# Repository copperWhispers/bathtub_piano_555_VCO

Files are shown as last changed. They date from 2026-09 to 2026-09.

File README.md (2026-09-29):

# bathtub_piano_555_VCO
bathtub tune-able analog keyboard based around a 555 timer chip used in PPM configuration.

Story Telling of the journey:
https://youtu.be/zMRLficPjbc

NE555:
https://www.ti.com/lit/ds/symlink/ne555.pdf

KiCAD Schematic and Layout attached.

Also attached a rough notes document which is the doc I wrote into as I designed this circuit, you can see it as an in depth technical version of the journey presented in the video.







References:

Ref1: notes and their frequencies
https://www.idrumtune.com/ultimate-guide-to-musical-frequencies/

Ref2: a complicated VCO + various waveform generators module. +/-12V
https://musicfromouterspace.com/analogsynth_new/VCO20090724REV0/VCO20090724REV0.html

Ref3: The basics of Oscillators and VCOs well explained step by step with circuits to be used +/12V
https://sound-au.com/project162.htm

Ref4: 555 Timer Datasheet.
https://www.ti.com/lit/ds/symlink/na555.pdf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

Ref5: Virtual grounds and examples.
https://tangentsoft.com/elec/vgrounds.html

Ref6: Potentiometers.
https://www.jotrin.com/technology/details/potentiometer-pinout-symbol-wiring-and-working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

Ref7: Inverting OPAMP topology.
https://electrosome.com/inverting-amplifier-using-opamp/

Ref8: RMS Formulae:
https://www.electronics-tutorials.ws/accircuits/rms-voltage.html

Ref9: Tim Stinchcomb Tri to SIne.
https://www.timstinchcombe.co.uk/index.php?pge=trisin

Ref10: TI Analog Engineer’s Pocket Reference.
https://www.ti.com/product-category/amplifiers/analog-engineers-pocket-reference-guide.html

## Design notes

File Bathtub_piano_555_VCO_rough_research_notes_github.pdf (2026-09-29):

I am working on making a video about a circuit that could generate a tone so that I can then build everything from there, I want this to be a sawtooth generator but it needs to produce set frequencies corresponding to the 12 fundamental notes.

## Music Theory:

Ref1

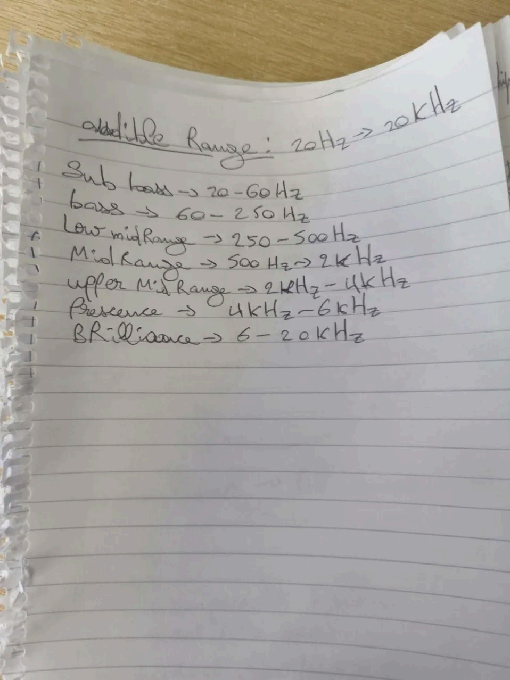
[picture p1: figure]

This sawtooth generator thus has to be variable easily so that I can get it to play any note,

## Sawtooth Generator:

I found out that sawtooth generators usually work by
having a current source charge up a capacitor,
followed by a comparator triggering once the capacitor get to a certain point,
The comparator’s signal then makes a switch which is responsible for discharging the capacitor activate,
This discharges the capacitor so that the cycle can start again, and the frequency is then set by how quickly you charge and discharge the capacitor.

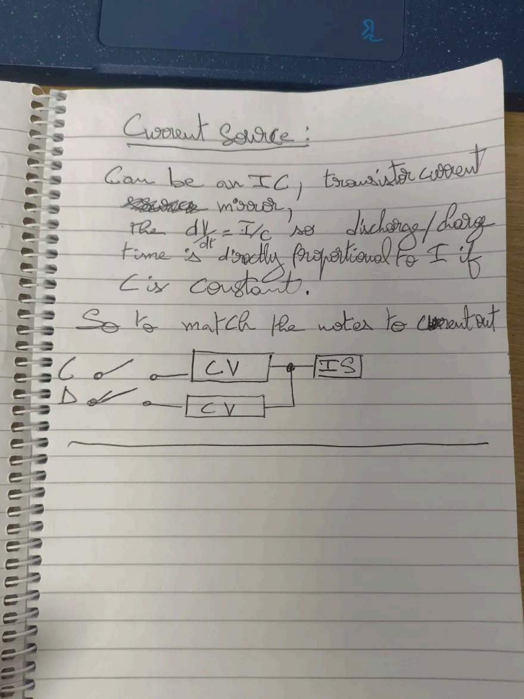
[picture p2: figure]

I then looked into how current sources work for this kind of utilisation, they can be coming from a transistor current mirror circuit,
I then drew that I would need a switch per note which would lead to a certain current source being provided to the capacitor for charging,
Or if using a voltage controlled oscillator then it would be a certain voltage per switch.

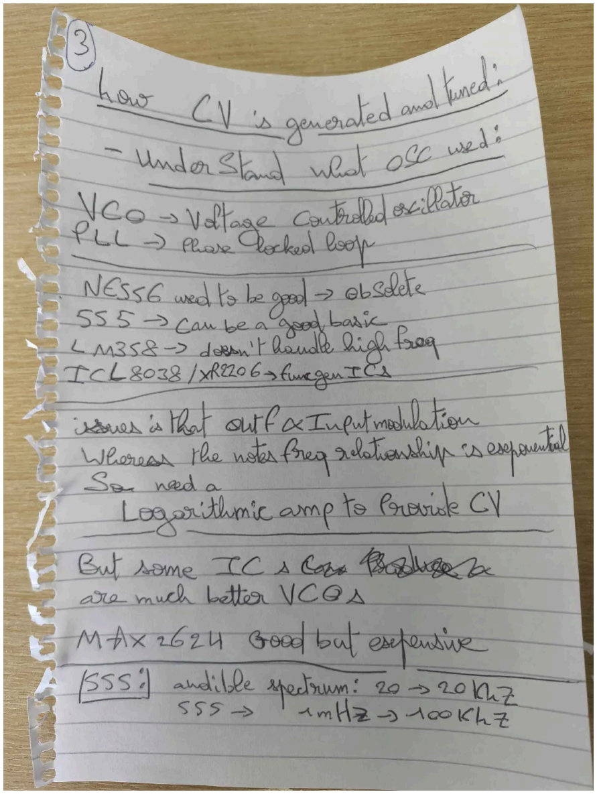
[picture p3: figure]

I then researched what oscillator I was going to use to get a clear idea of the control current or voltage required,
I ended up choosing the 555 timer for it’s low cost, high availability, high amount of documentation and the fact that it can handle 1mHz up to 100kHz, I learned about it from Ref3 and investigated the components listed in the article.

I then deep dived into the 555 timer through it’s datasheet , I came to learn that my desired configuration would be the PPM setup, and that the frequency which is related to the positioning of the pulses could be varied by applying a control voltage to the CONT pin,

This sounded very simple and so I decided to stick with this idea and just use trimmers on the input so that I could tune the instrument by having a frequency meter on the output and tuning each note individually,

I also discovered that the opamp seems to output a 5V pk to pk signal from the graphs, this is to be tested and I believe it is dependent on the power given to the ic, so I should check the datasheet further, but I will be more than fine with my virtual ground setup because it will be ac coupled which will get rid of the dc bias and thus the signal should fit in the virtual gnd’s realm.

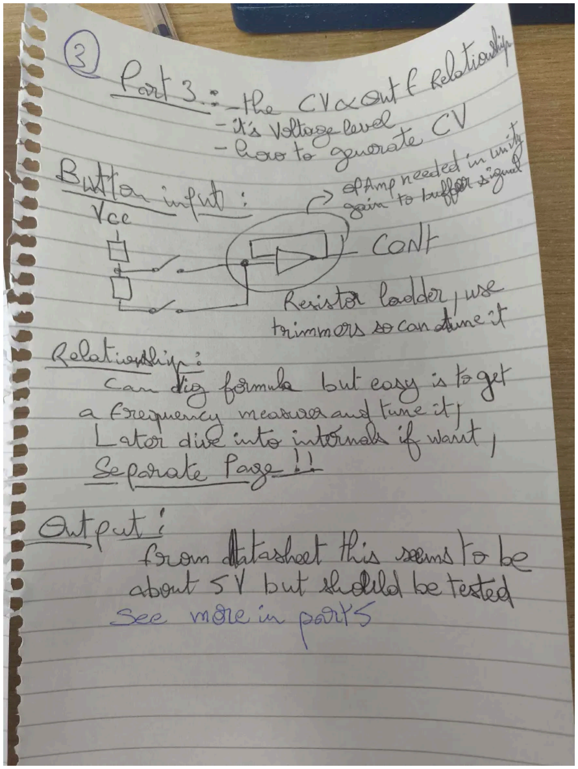
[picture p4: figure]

Here I looked deeper into what method I would use to control the input of the 555 timer to control it’s frequency,

I then thought I could analyse the formula in a deep dive format but that would have to wait as it is a complicated topic,

And lastly setup the plan regarding how I would morph the oscillator’s output to fit the audio amplifier,

I then looked at the datasheet and saw that the chip can handle 12V.

And thought I could also generate a virtual gnd from the 12V supply so that I can then morph the signal to my audio amp’s requirement through an inverting amplifier combined with an ac coupling capacitor.

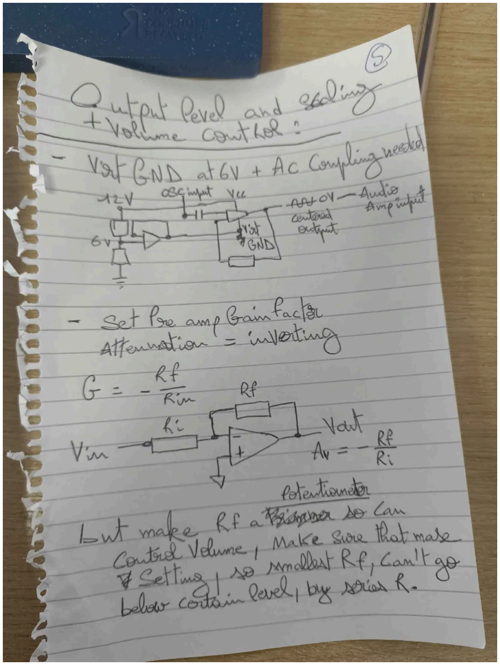
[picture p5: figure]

Once all of this was done, I drafted a quick inverting + virt gnd + ac coupling circuit idea which will be ready for testing, I also wrote down the maths for attenuation and circuit topology.

## Schematic Design:

### Part Organisation:

From my parts drawer I have the following components available:
NE5532ADR, I will use this chip for the pre amp. https://www.ti.com/lit/ds/symlink/ne5532.pdf?ts=1787995293486&ref_url=https%253A%252 F%252Fcz.mouser.com%252F (https://www.ti.com/lit/ds/symlink/ne5532.pdf?ts=1787995293486)

TL072HIDDFR, I will use this chip for the Virt GND buffer.https://www.ti.com/lit/ds/symlink/tl071h.pdf?ts=1788006096240&ref_url=https%253A%252F%252Fwww.mouser.de%252F (https://www.ti.com/lit/ds/symlink/tl071h.pdf?ts=1788006096240)

All sorts of passives,
NE555.

### 12V PSU:

For now this is just a 12V supply from mains AC, nothing to do here,

### 6V Vdiv Virt GND:

This is about taking the 12V rail, having a Voltage divider network and then buffering the mid point to be used as a Virtual mid point ground,

From Ref5:

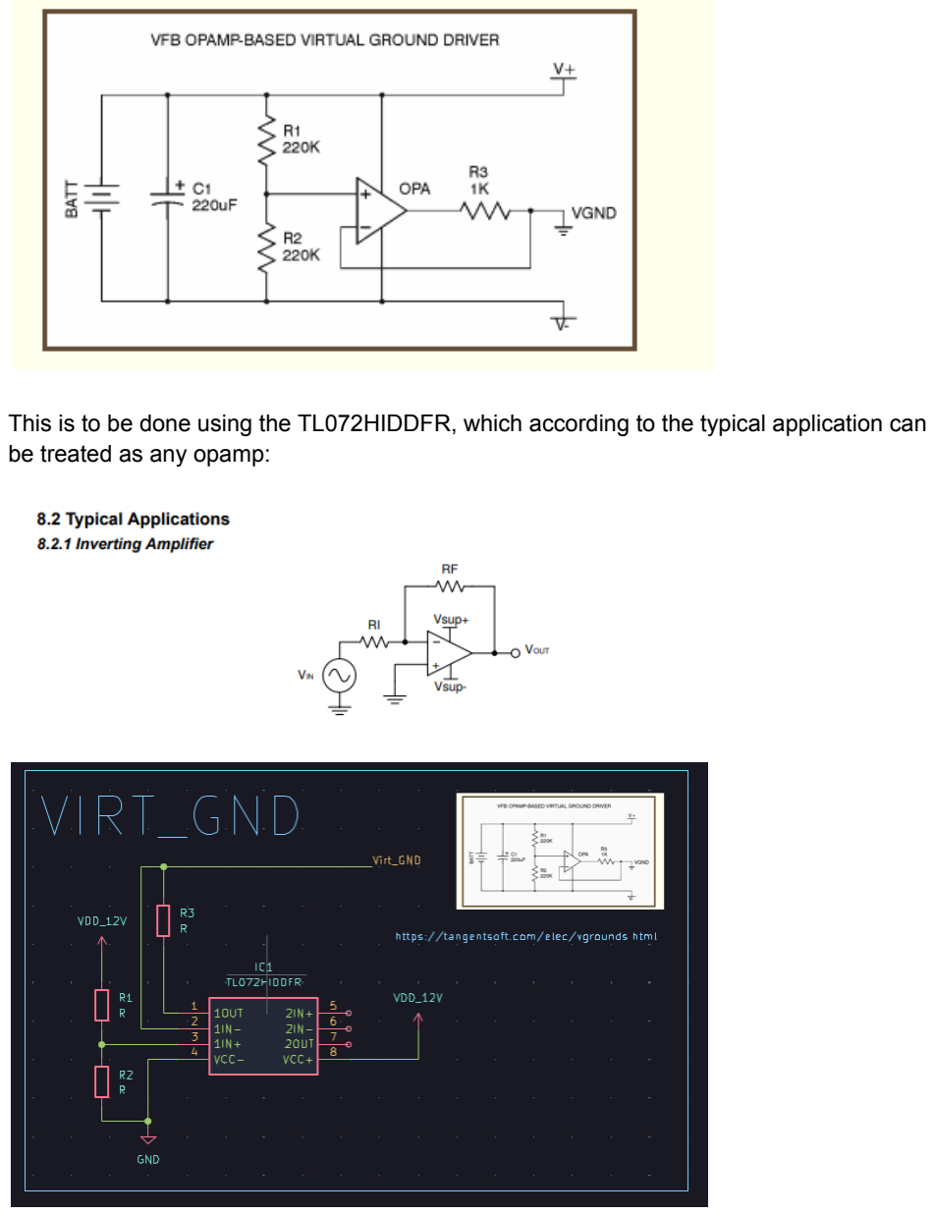
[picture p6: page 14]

This is to be done using the TL072HIDDFR, which according to the typical application can be treated as any opamp:

### Resistors Ladder with Buttons + Buffered:

For this we need to use trimmers so that we can tune the instrument, as I am bypassing the maths for efficiency sake I will be setting an arbitrary trimmer value on the breadboard and seeing if it works then just adjust later if needed.
From Ref6, this is how a potentiometer works:

So you have the input go to pin 1, then the follow up goes to pin2 and then GND to pin 3. This creates a voltage divider, which means that pin 2 will output a variable voltage set to wherever you have the point, we don’t actually need a cascading ladder which would induce issues such as adjusting the first trimmer would cascade the values of the next but here instead we can have each note be its own trimmer, which makes the job much simpler.

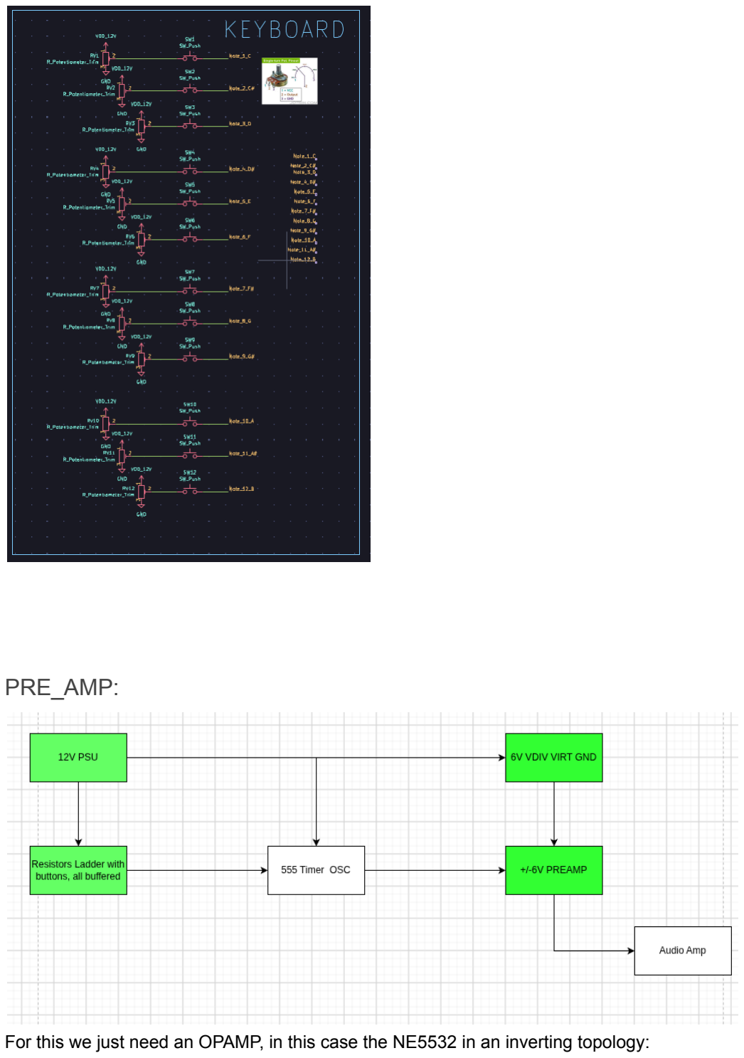
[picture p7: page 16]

### PRE_AMP:

For this we just need an OPAMP, in this case the NE5532 in an inverting topology:

Gain is then: Gain = - (Rf / R1)
So if we predict the 555 timer to output 5V and we want that to become 0.4V: 0.4 / 5 = 0.08,
Setting Rf to 100k for reference we get:
-0.08 = (100k / R1) Which transforms into: R1 = -(100k / (-0.08))
This would mean R1 = 1,250,000, which is too big of a value for my liking, so I will change RF to 8k and now R1 is 100k, clean numbers.
The negative sign here indicates that the signal flips polarity.

However I didn’t account for the fact that this is about comparing 0.4Vrms with whatever the rms of 5V is, so they need to both be rms not one in pkpk and one in rms,

Rms formulae:

So 5Vpk = ~ 3.5Vrms

So now the attenuation is 0.4 / 3.5 = ~ 0.1,
R1 = -(10k / (-0.1))
R1 = 100k

I rounded some figures as it doesn’t need to be completely accurate at this stage and there will be some breadboarding done later too

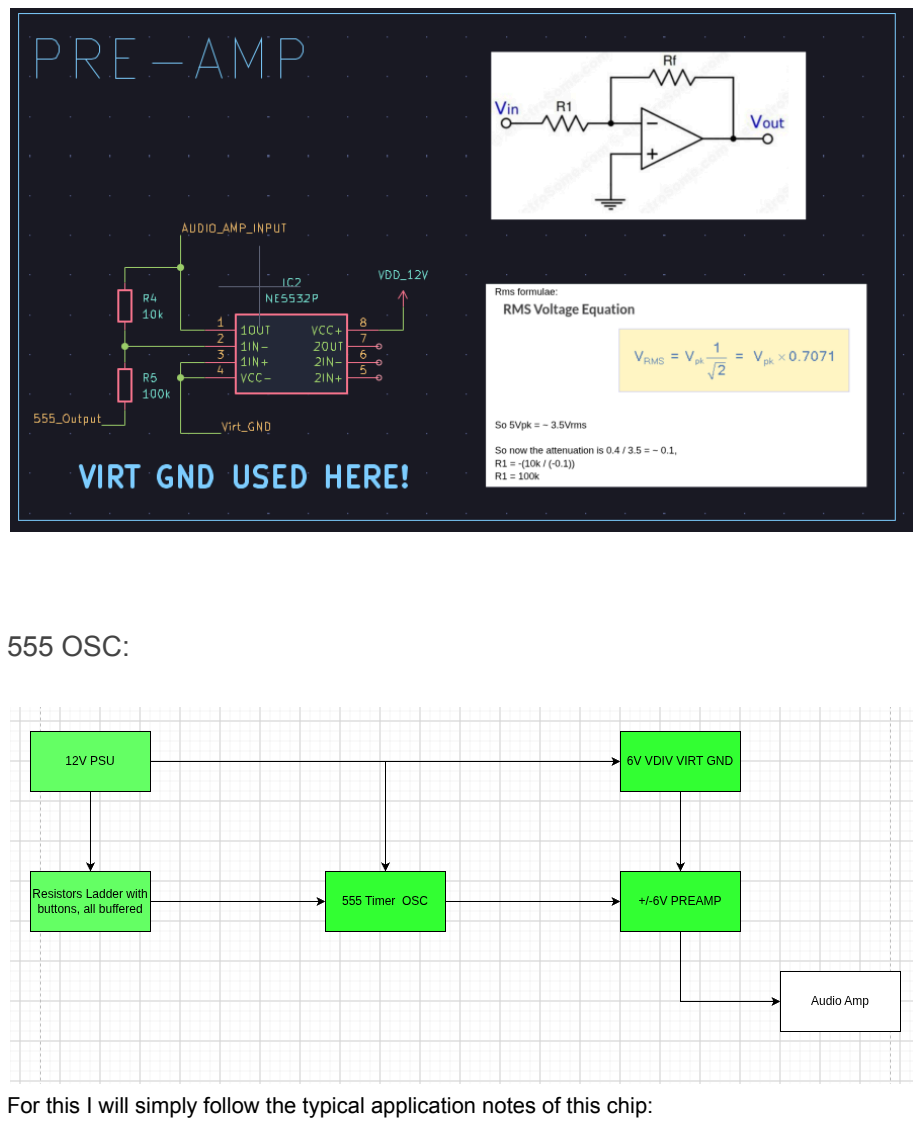
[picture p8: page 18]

### 555 OSC:

For this I will simply follow the typical application notes of this chip:

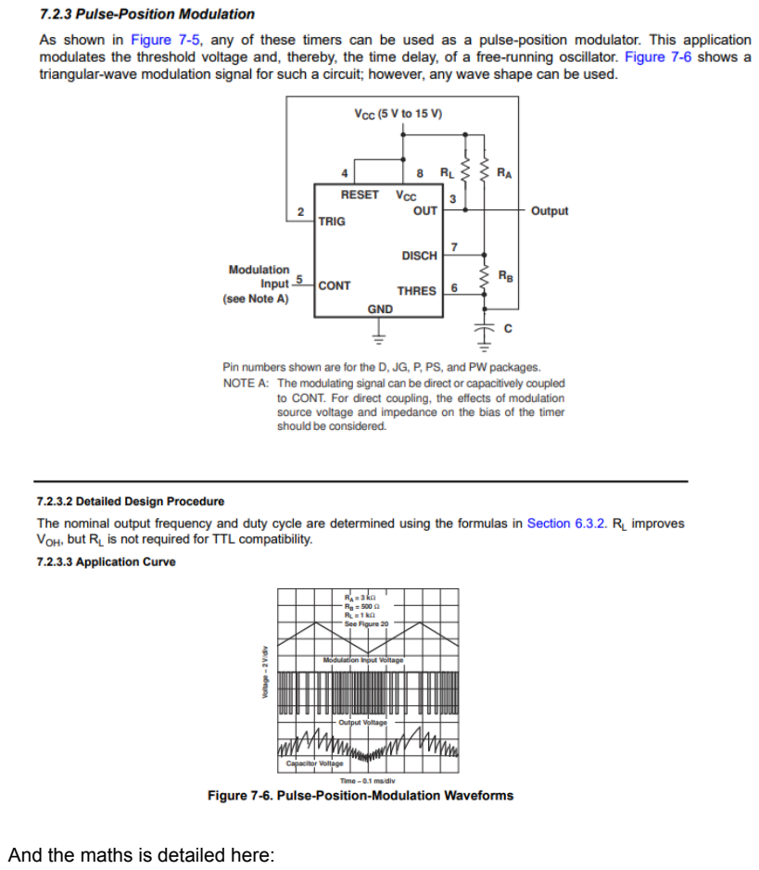
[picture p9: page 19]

And the maths is detailed here:

So from my understanding frequency = 1.44 / (RA + 2RB) * C

However for PPM configuration:

The modulation input changes the voltage thresholds which then changes the frequency as the charge/discharge will happen at a different rate, so this seems like a bit of a rabbit hole and I think the most efficient way to solve this is to follow the typical application graph values of:
RA = 3k ohms, RB = 500 ohms, RL = 1k ohms

Then on a breadboard setup just one pot trimmer Vdiv input to the modulation input, figure out what R values give me C3 through the 12 notes up to B3, take notes of them and then select the trimmers based on this experiment.

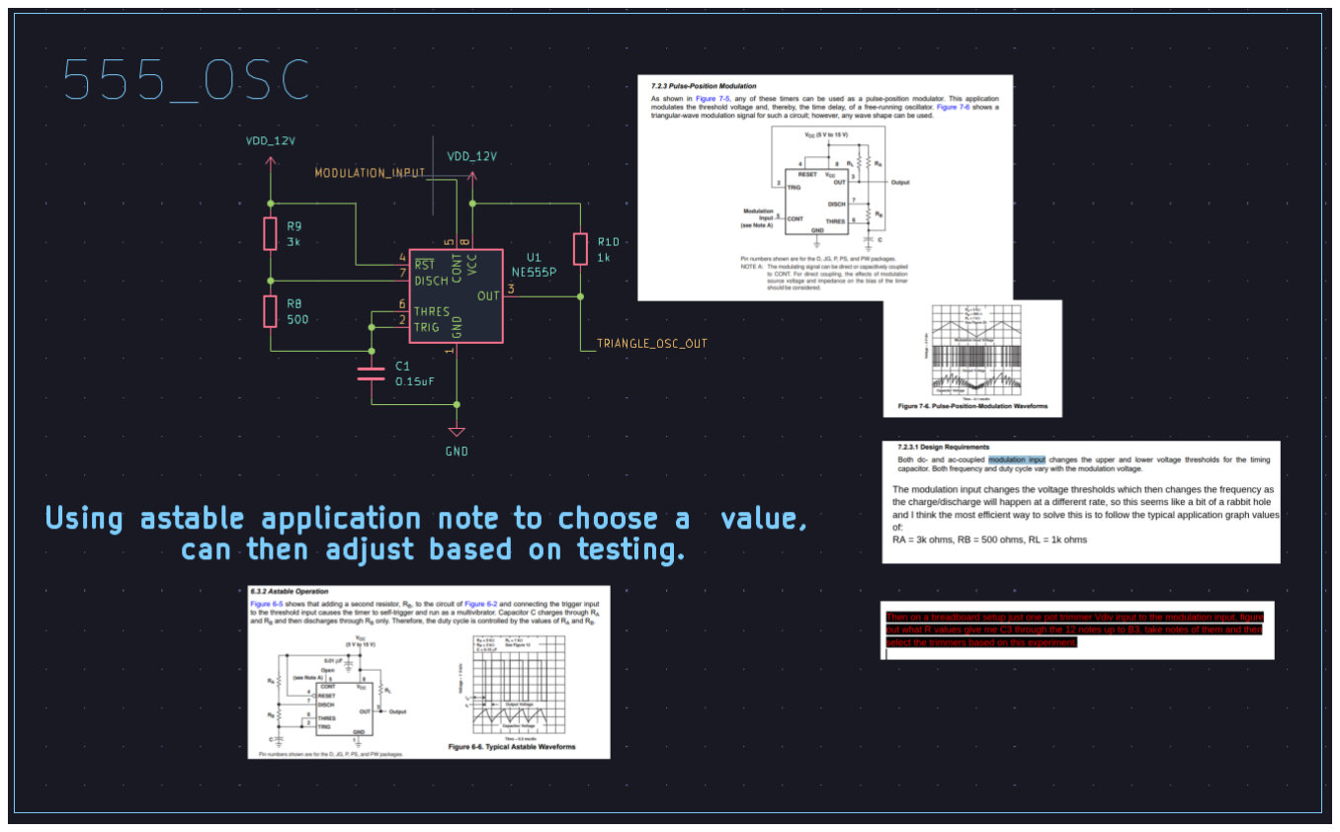
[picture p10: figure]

### Tidy up and Connect to Audio Amp:

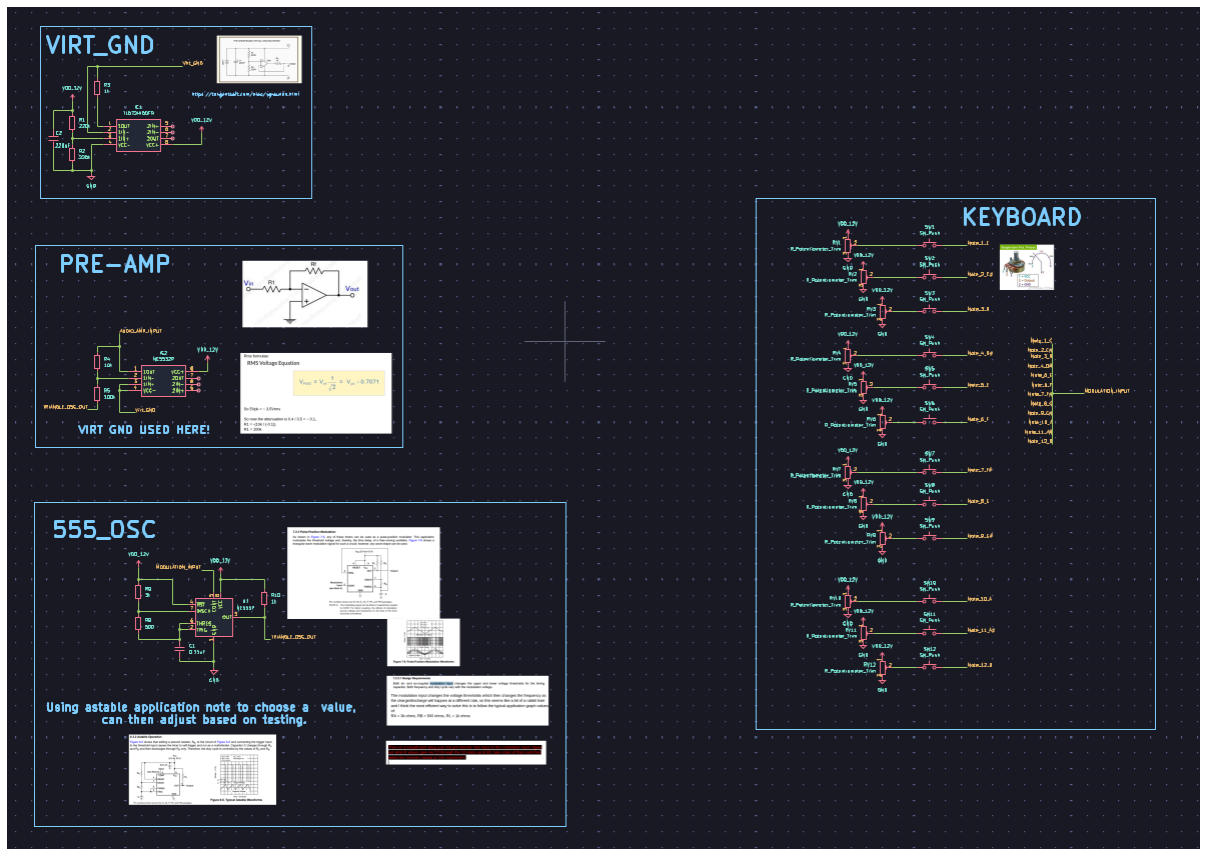
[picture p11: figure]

## Design Error, Research Rectification, Learning:

### In/Out Impedance:

I then realised through another build that potentially the virtual ground and pre-amp aren't actually needed,

Maybe just a Resistor divider would be sufficient for converting the 12V PWM output to the input required for the audio amp,

Then an AC Coupling cap is used to remove the DC offset and center the signal around 0V,

So I came to this decision by learning about Load and Source impedance and it’s ratios relationship with the delivered voltage:

Load Z / Source Z = Load to Source Z ratio.

VL = VS * (RL / RS + RL) -> so the resistors ratio define the percentage of V that is delivered.
Here’s a model of the ratio and its relationship with delivered voltage:

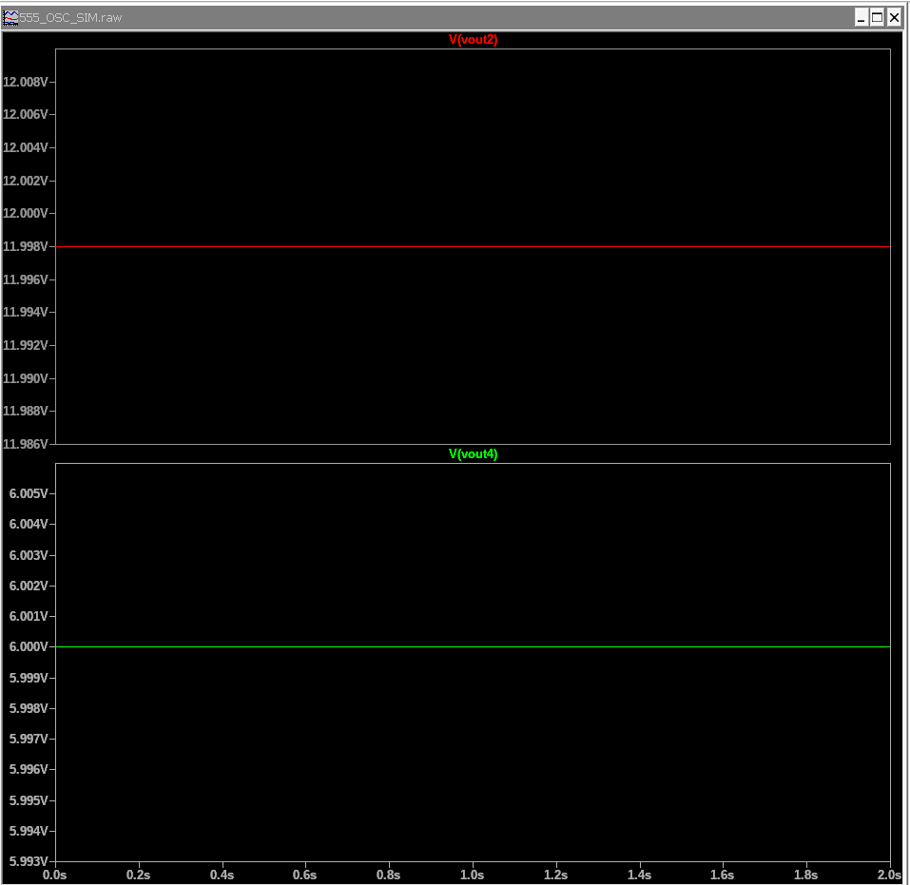
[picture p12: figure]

As you can see, having a good load to source ratio means that more voltage is present at the load, if the load = source then you would lose half of the voltage at the load, this is crucial for high precision sensing equipment as the sample is already so small that we want to obtain as much of it as possible inside of the sensing equipment to amplify it.

TPA3116 input impedance and cutoff calculations:

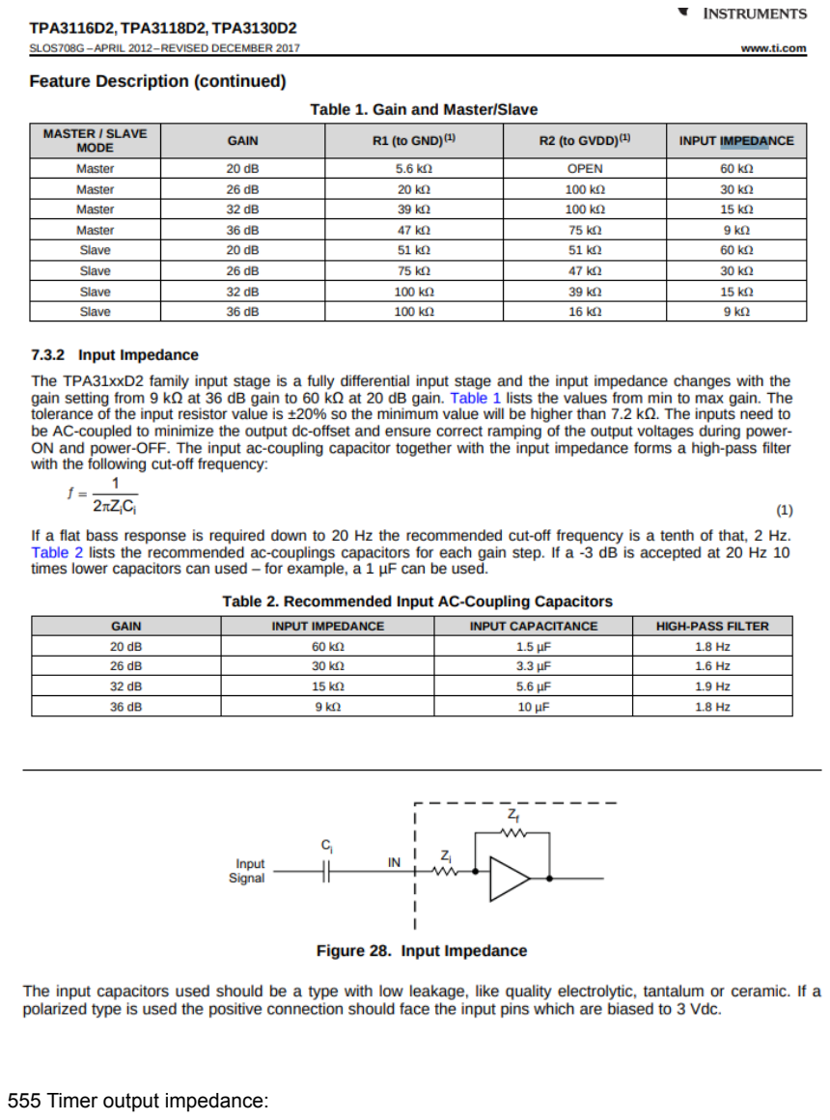
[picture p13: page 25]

555 Timer output impedance:

This isn’t a perfect science but estimating we can see that for 25 degrees C the voltage drop goes from 1.3V to 1.5V in 40mA, that is a 0.2V change in 40mA, R = 0.2/0.04 = 5 ohms

### AC Coupling:

I also got to learn about AC coupling, and how a coupling cap in combination with the load impedance acts as a high pass filter configuration, a higher capacitance cap is thus then resulting in a better preservation of the lower frequency constituents of an audio waveform,

Maths:
Fc = 1/(2piRC)

Model:

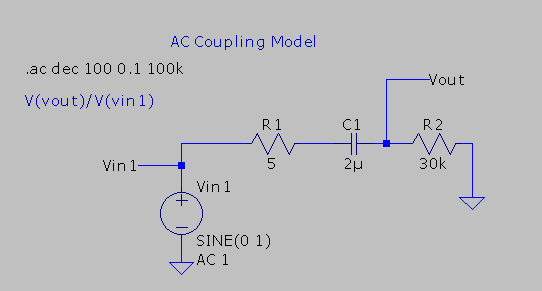
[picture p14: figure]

## 555 PPM Frequency calculation:

I also thought I’d seize this opportunity for a change to do the frequency calculation properly by:
- Figuring out the mathematics for it from the datasheet,
- Plotting breadboard test values and comparing it with the maths,
- Deciding whether I make the buttons a stable PCB or a vero board with potentiometers, this will depend on the stability of the system with respect to temperature and perhaps other unknown impactful variables.

### 555 PPM F Mathematics:

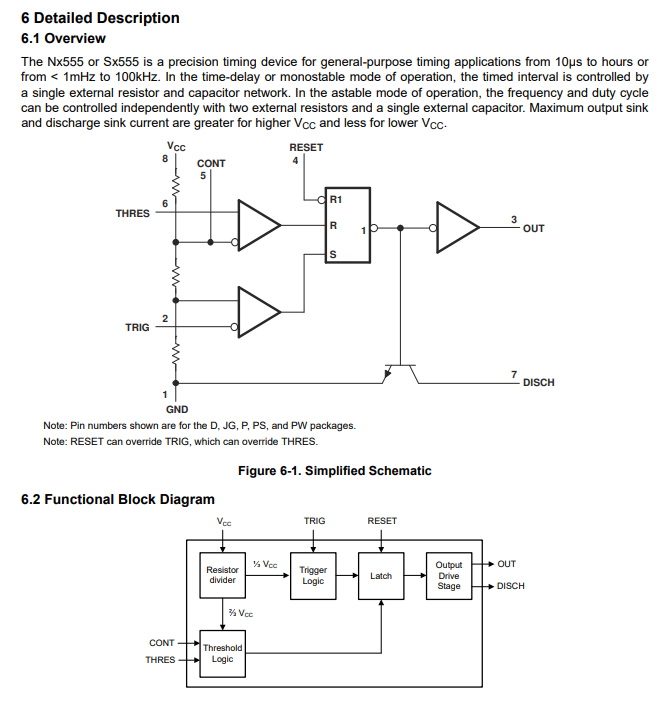
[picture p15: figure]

The note here mentions that the effects modulation of the source voltage and impedance of the timer should be considered.

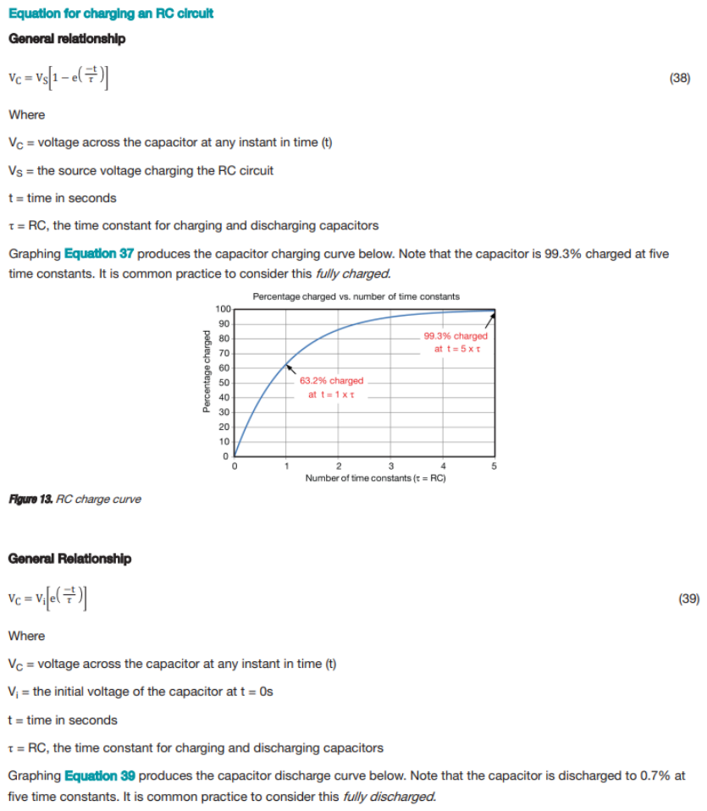
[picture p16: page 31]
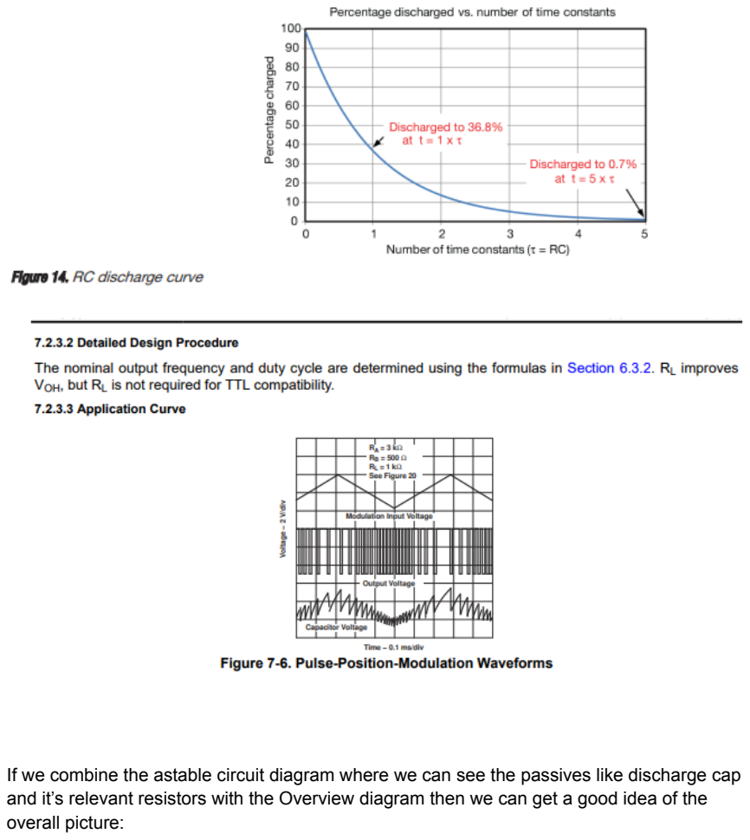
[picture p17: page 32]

If we combine the astable circuit diagram where we can see the passives like discharge cap and it’s relevant resistors with the Overview diagram then we can get a good idea of the overall picture:

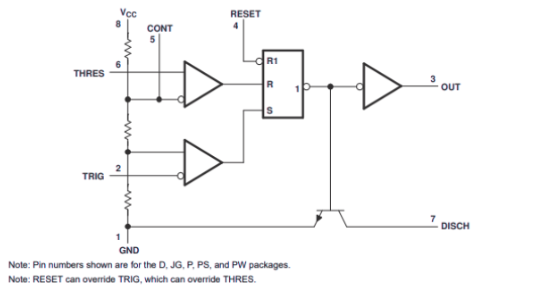
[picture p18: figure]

There is an SR latch in the overview which needs analyzing, but we can see that DISCH would get pulled to GND level when the SR triggers and we know that that triggering is due to the two different threshold point being reached,
If we look at the astable circuit we can see that discharge is controlling the point above the Threshold and trigger points and englobes the caps, thus if DISCH is set to GND level then the cap would stop being powered and would discharge into the grounded load

### 555 PPM F Breadboard Testing:

### 555 PPM F Design Decision:

## Full circuit simulation with new concept:

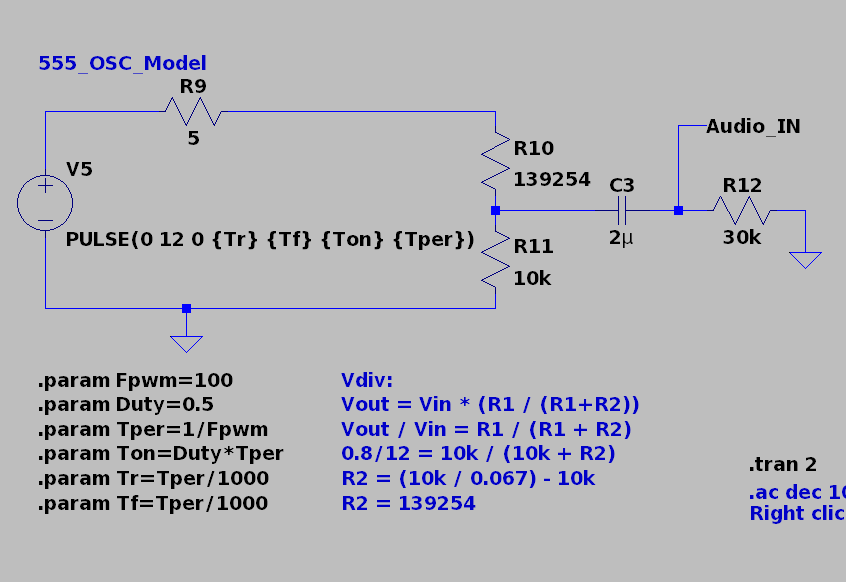
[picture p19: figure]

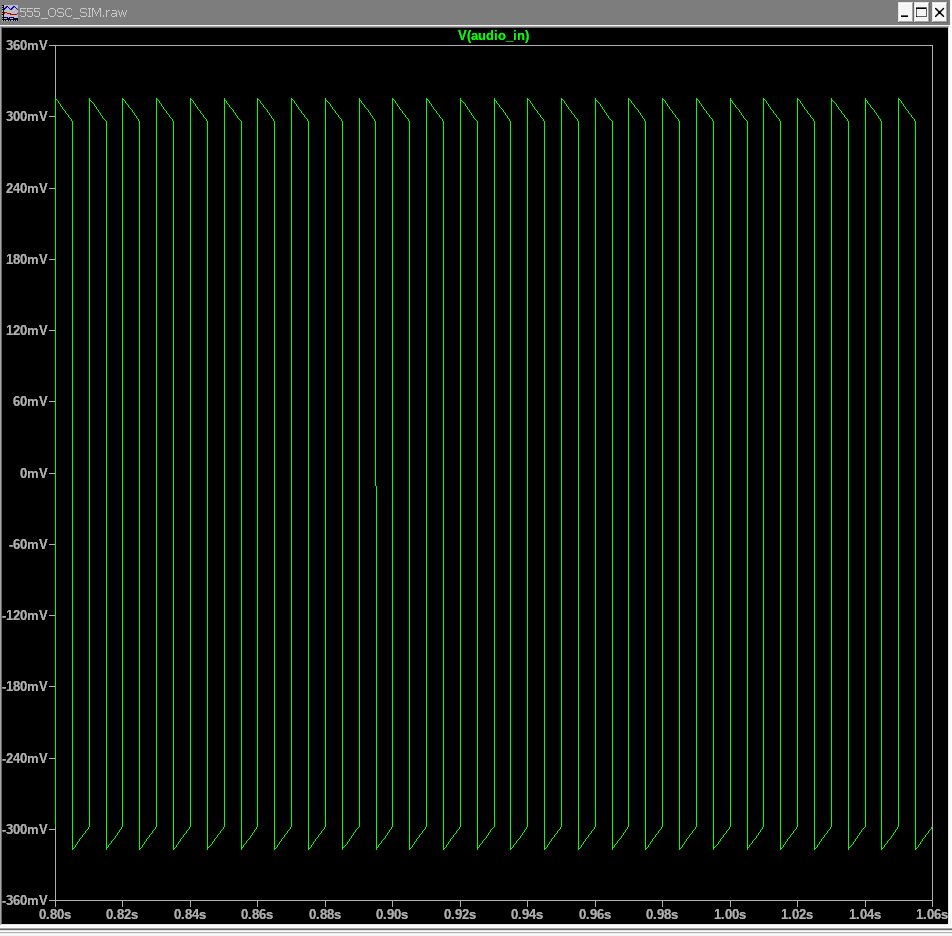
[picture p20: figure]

New schematic design:

## Breadboard prototyping:

Testing Results:
- Built using slightly different passive values,
- Forgot about the AC coupling on the schematic, added 100nF on breadboard for testing,
- It seems the pulse to pulse gap changes based on potentiometer settings but the pulses do look weird,
- Can’t easily test with scope due to Earth induced GND bridging,

Some measurements:
I tested every section block by block in isolation,

Virt GND, CORRECT, 6V is outputted from the chip, to be fed as GND for the attenuation circuit, and we see both + and - 6V.

Buttons, CORRECT, based on current circuit, when no button is pressed V = 0, when I press a button then I get the voltage from the VDIV

PRE-AMP, ISSUE, here when trying to scope the output, virt gnd collapses and the output becomes centered around the wrong value, however it seems the circuit is behaving correctly. HOWEVER, when scoping using a non grounded probe, the behaviour seems correct, the pre amp outputted pulse is about 1.5pk, whereas the output of the 555 seems to be 12.5V, thus the attenuation is correct, I just assumed that the 555 would output 5Vpk and learnt that it actually outputs Vcc.
When powering the circuit with 5V, we see the correct behaviour of the 555 timer outputting a 5Vpk waveform and the preamp outputting a 1Vpk centered at 2.5V.

So now, fixes would involve:
- Correcting the attenuation to handle a 12Vpk waveform and attenuating it to 0.4Vrms
- Researching connecting this module with the audio amp module and in particular how GND should be handled.
- Add AC coupling components and whatever other issues may be found.

This is what I got after plotting the values:

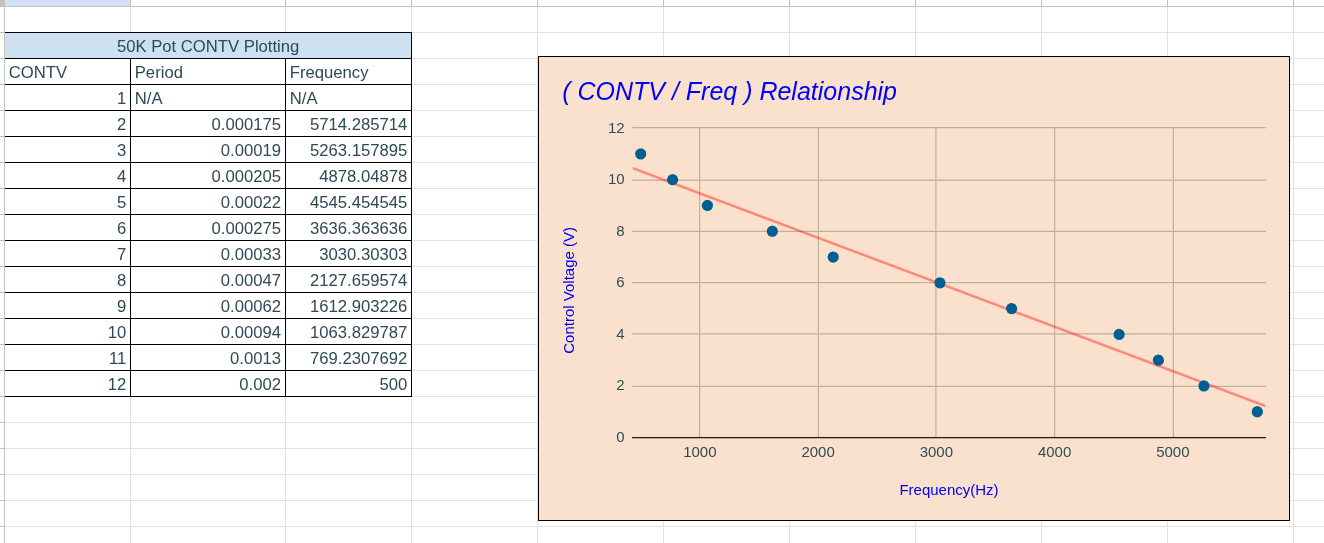
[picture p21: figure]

This is the note frequency calculations, as we can see I can play from C5 to C6 for a full octave of notes by just going from 10V to 12V, this is sufficient for my use case so the next step is to calculate the the resistor values to get a 10/12V CONT input:

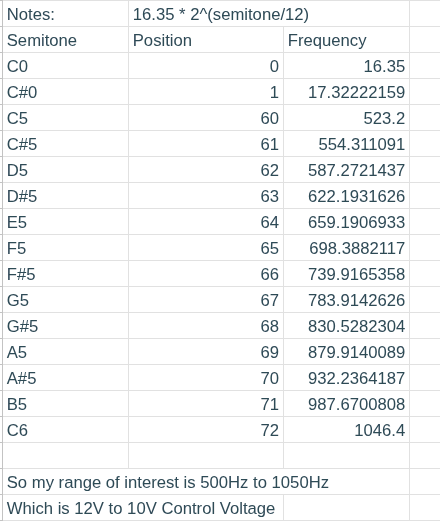
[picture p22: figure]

However recalling the following from the datasheet:

We can see that the frequency is relative to the RA and RB value, where increasing RA and RB would lead to a smaller frequency value,
we can also see that the duty cycle is relative to ratio of RA to RB,

So, keeping C as the current 0.15uF and aiming for a frequency of 16.35Hz so that we can reach lower octaves:
16.35 = 1.44 / ( (Rfactor) * 0.15u )
Where Rfactor = RA + 2RB
Thus:
Rfactor = 1.44 / ( 16.35 * 0.15u)
Finally:
RA + 2RB = 587k

Waveform referred duty cycle refers to the ratio of time the waveform is high in a time period: tH / T.
Output driver duty cycle refers to the low: tL / T

So aiming for a x>50% duty cycle, since 50% wouldn’t be possible without RA being 0.

We can try 51%:
0.51 = RA + RB / (587k)
0.51 * 587k = RA + RB
299370 = RA + RB
If we set RB as 100k for reference then RA can be equal to 200k.

In the future we can look at the effects of duty cycle sweeping on sounds.

However as 16.37Hz is C0 and I want something more mid range I will shift this to 130.8Hz or C3:

130.8 = 1.44 / ( (Rfactor) * 0.15u )

Where Rfactor = RA + 2RB
Thus:
Rfactor = 1.44 / (130.8* 0.15u) Finally:
RA + 2RB = 73k394

0.51 = RA + RB / (73k394)
0.51 * 73k394 = RA + RB
37k430.94 = RA + RB
If we set RB as 10k for reference then RA can be equal to 27k.

I then simulated voltage dividers to ensure I was getting the maths correct to obtain voltages from 12V to 10V:

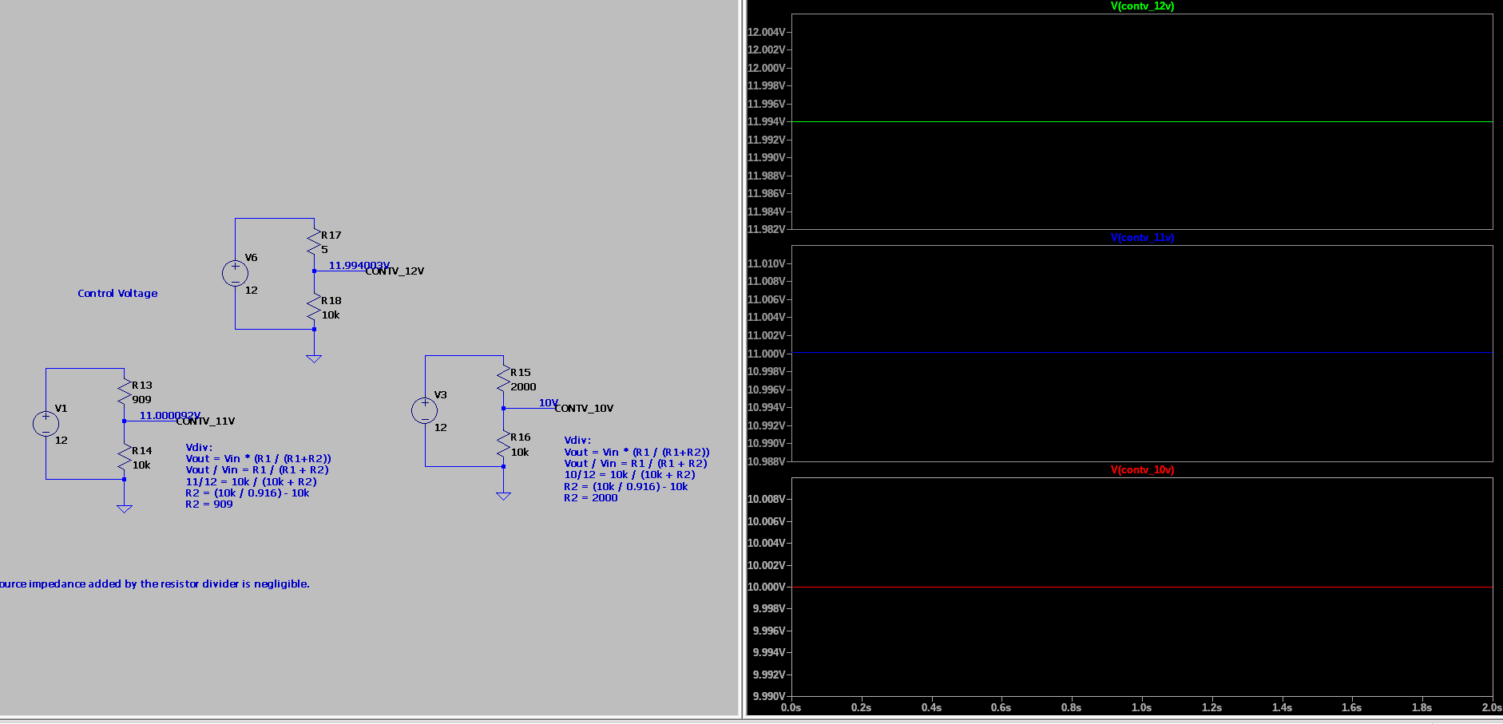
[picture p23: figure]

From this I figured a 2k pot in series with a 10k resistor where the midpoint between the 2 is gnd would be a good test to figure out the values needed for notes going from C5 to C6:

The CONT input which get controller by a pot trimmer needs Resistors at the top and bottom to limit the input so that it fits within 10V-2V to avoid driving it on the absolute edges which can cause some stalling.

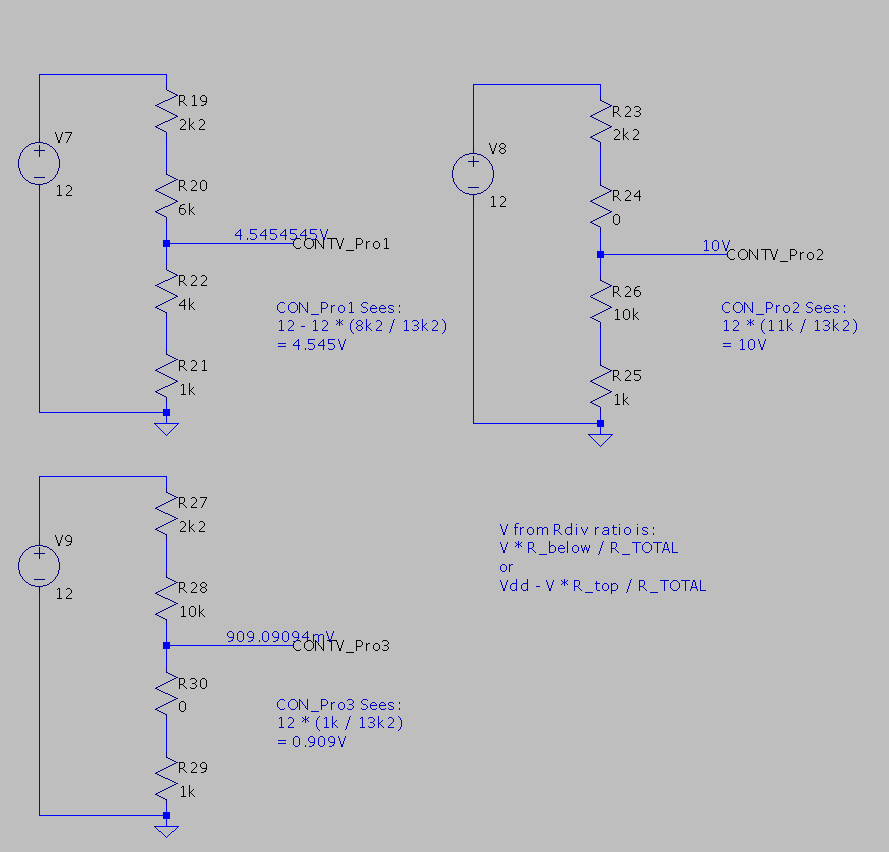
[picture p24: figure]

The 555 timer is named after 5 series resistors in it’s internal structure, this results in Pin5 (CONT) having a 3k3 impedance,

## References:

References:
Ref1: notes and their frequencies https://www.idrumtune.com/ultimate-guide-to-musical-frequencies/

Ref2: a complicated VCO + various waveform generators module. +/-12V https://musicfromouterspace.com/analogsynth_new/VCO20090724REV0/VCO20090724RE V0.html

Ref3: The basics of Oscillators and VCOs well explained step by step with circuits to be used +/12V
https://sound-au.com/project162.htm

Ref4: 555 Timer Datasheet. https://www.ti.com/lit/ds/symlink/na555.pdf?ts=1779184670697&ref_url=https%253A%252F %252Fwww.ti.com%252Fproduct%252FNA555

Ref5: Virtual grounds and examples.
https://tangentsoft.com/elec/vgrounds.html

Ref6: Potentiometers.
https://www.jotrin.com/technology/details/potentiometer-pinout-symbol-wiring-and-working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 (https://www.jotrin.com/technology/details/potentiometer-pinout-symbol-wiring-and-working)

Ref7: Inverting OPAMP topology. https://electrosome.com/inverting-amplifier-using-opamp/

Ref8: RMS Formulae:
https://www.electronics-tutorials.ws/accircuits/rms-voltage.html

Ref9: Tim Stinchcomb Tri to SIne. https://www.timstinchcombe.co.uk/index.php?pge=trisin

Ref10: TI Analog Engineer’s Pocket Reference. https://www.ti.com/product-category/amplifiers/analog-engineers-pocket-reference-guide.htm l

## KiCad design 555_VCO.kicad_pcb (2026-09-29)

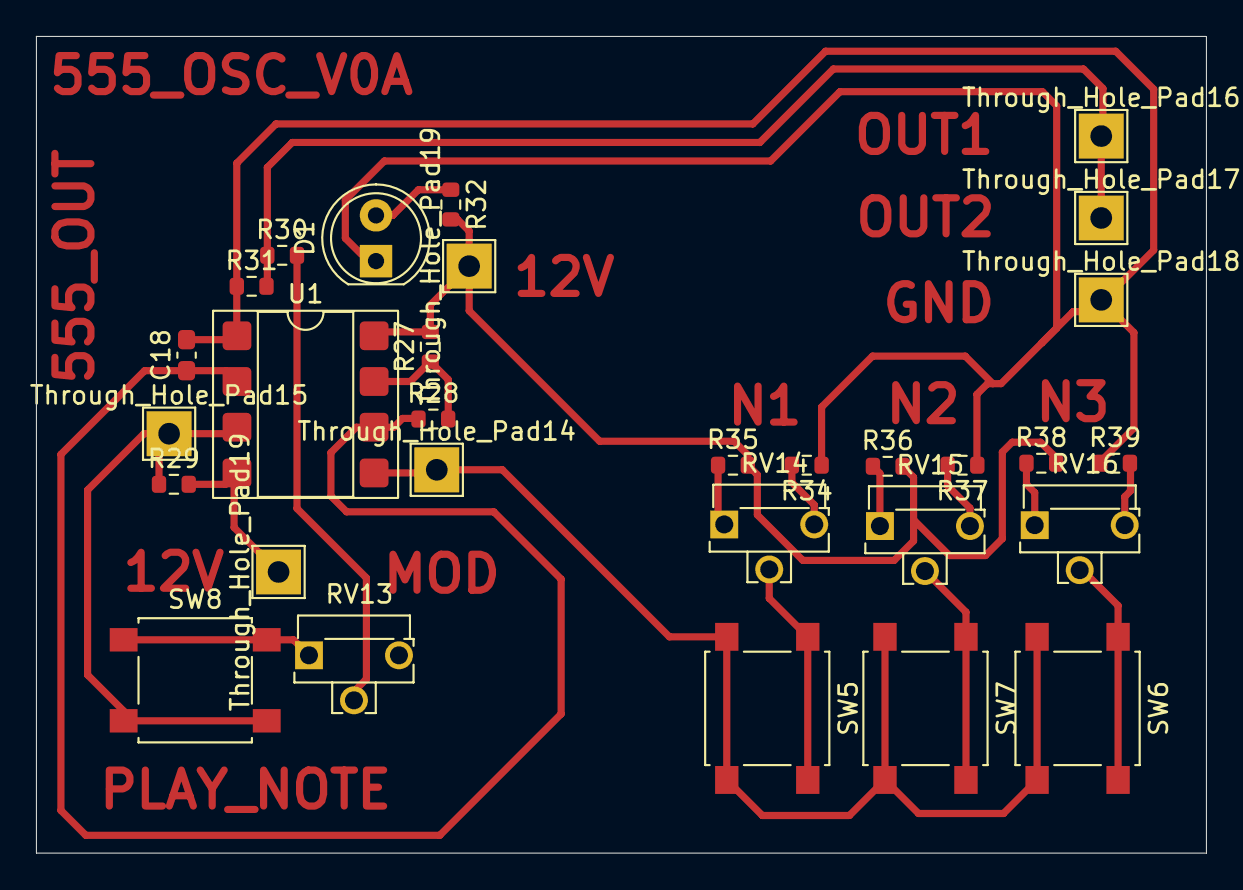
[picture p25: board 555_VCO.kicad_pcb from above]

Board: 2 copper layers, 65.0 x 45.4 mm, 30 parts (0 on the bottom side), 19 nets.

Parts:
C18: 0.15u; C_0603_1608Metric_Pad1.08x0.95mm_HandSolder
D1: LED; LED_D5.0mm
R27: 27k; R_0603_1608Metric
R28: 10k; R_0603_1608Metric
R29, R32, R34, R37, R39: 1k; R_0603_1608Metric
R30: 1k4; R_0603_1608Metric
R31: 100; R_0603_1608Metric
R35, R36, R38: 2k2; R_0603_1608Metric
RV13: 500k_trim; Potentiometer_Runtron_RM-063_Horizontal
RV14, RV15, RV16: 10k_trim; Potentiometer_Runtron_RM-063_Horizontal
SW5, SW6, SW7, SW8: Push_Button; SW_SPST_B3S-1000
Through_Hole_Pad14, Through_Hole_Pad15, Through_Hole_Pad16, Through_Hole_Pad17, Through_Hole_Pad18, Through_Hole_Pad19, Through_Hole_Pad19#2: TestPoint_THTPad_2.5x2.5mm_Drill1.2mm
U1: NE555P; DIP-8_W7.62mm_SMDSocket_SmallPads

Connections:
/555_OSC_OUT: R29.1, SW8.2, Through_Hole_Pad15.1, U1.3 (OUT)
/AUDIO_AMP_INPUT: R30.1, R31.2, Through_Hole_Pad16.1, Through_Hole_Pad17.1
/MODULATION_INPUT: SW5.2, SW6.2, SW7.2, Through_Hole_Pad14.1, U1.5 (CONT)
GND: C18.2, D1.1, R31.1, R34.1, R37.1, R39.1, Through_Hole_Pad18.1, U1.1 (GND)
unnamed: D1.2, R32.1
unnamed: R30.2, RV13.2
unnamed: R34.2, RV14.3
unnamed: R35.1, RV14.1
unnamed: R36.1, RV15.1
unnamed: R37.2, RV15.3
unnamed: R38.1, RV16.1
unnamed: R39.2, RV16.3
unnamed: RV13.1, SW8.1
unnamed: RV14.2, SW5.1
unnamed: RV15.2, SW7.1
unnamed: RV16.2, SW6.1
unnamed: R27.1, R28.2, U1.7 (DISCH)
unnamed: C18.1, R28.1, U1.2 (TRIG), U1.6 (THRES)
VDD_12V: R27.2, R29.2, R32.2, R35.2, R36.2, R38.2, Through_Hole_Pad19.1, Through_Hole_Pad19#2.1, U1.4 (~RST), U1.8 (VCC)
